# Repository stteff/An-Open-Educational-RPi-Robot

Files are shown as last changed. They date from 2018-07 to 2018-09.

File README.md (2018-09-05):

# Table of Contents

* [What is OpEdRo](#opedro-an-open-educational-rpi-robot)
* [Main Components](#main-components)
* [Circuit Diagram](#circuit-diagram)
* [(Raspberry Pi) Software Prerequisites](#raspberry-pi-software-prerequisites)
  * [Step 1: Installing and Setting up Raspberry Pi's Operating System](#step-1-installing-and-setting-up-raspberry-pis-operating-system)
  * [Step 2: Installing Necessary Python Libraries](#step-2-installing-necessary-python-libraries)
* [Remote Access Rapsberry Pi's Command Line Interface (CLI)](#remote-access-rapsberry-pis-command-line-interface-cli)
* [The Control Computer](#the-control-computer-----)
* [Scratch Project](#scratch-project-----)
* [Licenses](#licenses)

---

# [OpEdRo] An-Open-Educational-(RPi)-Robot

An Educational Robotic Platform, Raspberry Pi based, using Open Technologies. Remotely programmable from Scratch to move specific distances, to turn specific angles, to get distance from obstacle, to get environment temperature, to speak text and contents of variables in more than 30 languages.

---

*`This project is in active development. Additions will be taking place on a regular basis`*

---

## `OpEdRo:-----`
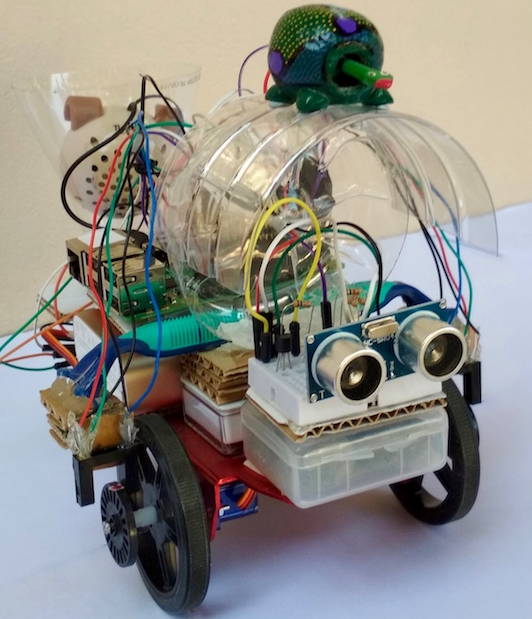
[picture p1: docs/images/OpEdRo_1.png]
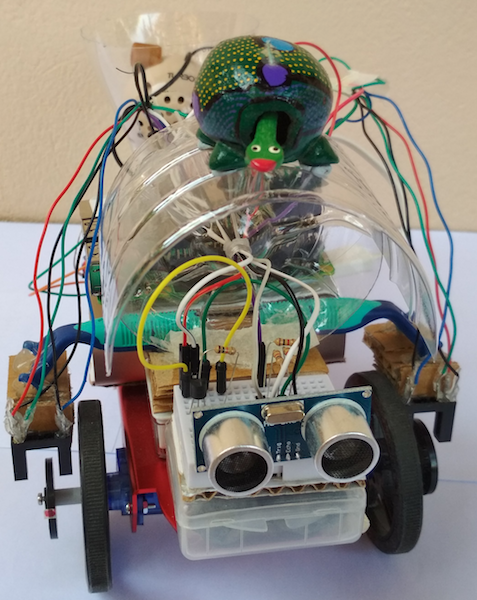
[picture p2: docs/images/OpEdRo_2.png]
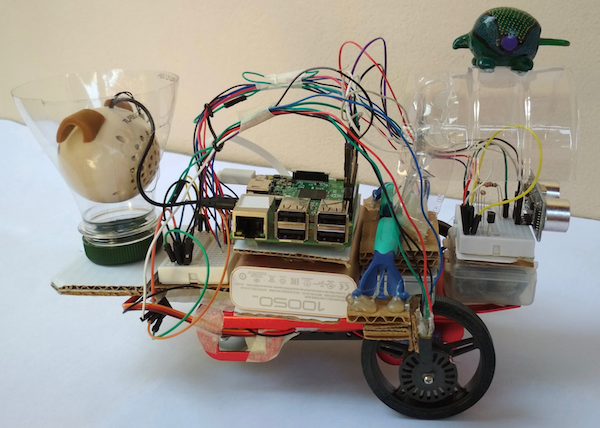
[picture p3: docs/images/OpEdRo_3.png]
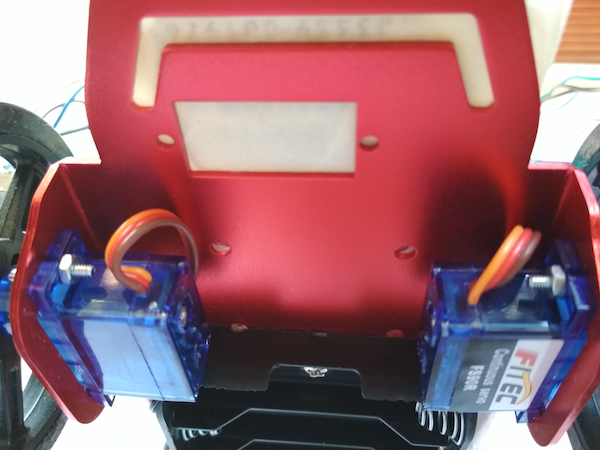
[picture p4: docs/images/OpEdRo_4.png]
     
### Main Components:

chassis Raspberry Pi 3 servo motor photoelectric Encoder disk servo wheel digital thermometer ultrasonic sensor ball caster Battery holder

  * A robot chassis appropriate to host the following parts
  * A Rapsberry Pi 3 model B
  * 2 continuous rotation micro servo motors, fitable to robot chassis
  * 2 photoelectric sensors
  * 2 encoder disks
  * 2 servo mount wheels
  * 1 digital thermometer (DS18B20)
  * 1 ultrasonic distance sensor (HC-SR04)
  * 1 ball caster
  * 1 battery holder for 4xAA to power the servos
  * 1 power bank for Raspberry Pi
  * 1 small portable speaker with 3.5 mm jack (for the speech engine)
  
### Circuit Diagram
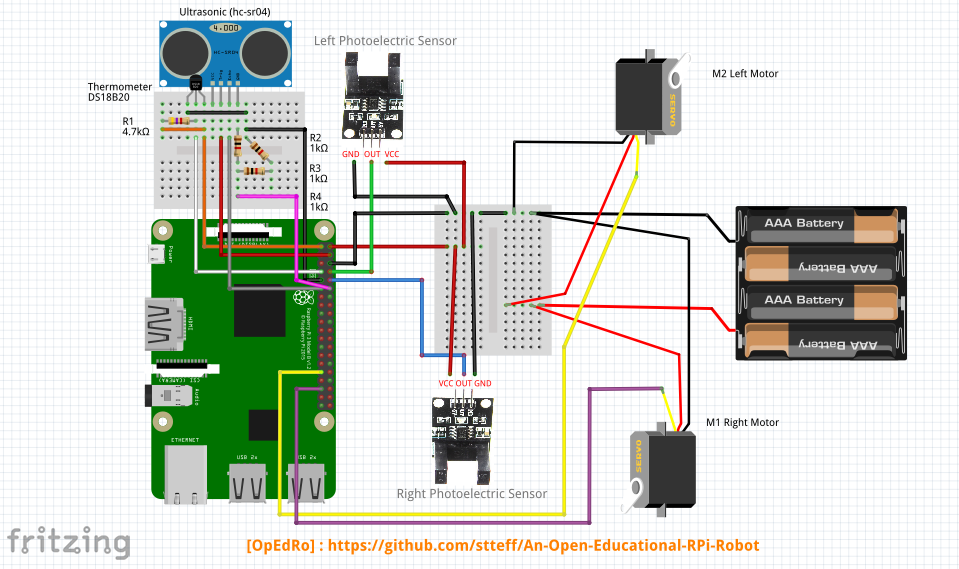
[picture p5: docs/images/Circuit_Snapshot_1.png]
Circuit diagram
  
  
### (Raspberry Pi) Software Prerequisites: 

  * Operating system
    * Raspbian Jessie or Stretch Lite (Lite version uses lower computer resources)
  * Python 2.7.x (inclluded with OS)
  * Python packages / modules:
    * [RPi.GPIO](https://sourceforge.net/p/raspberry-gpio-python/wiki/Home/ "RPi.GPIO Wiki") (a class to control the GPIO on a Raspberry Pi, included with OS)
    * [pigpio](http://abyz.me.uk/rpi/pigpio/index.html "The pigpio Documentation") (a library supporting hardware timed servo pulses)
    * [scratchpy](https://github.com/pilliq/scratchpy "Python interface to Scratch") (a python client for Scratch)
    * [espeak](http://espeak.sourceforge.net/ "espeak Documentation") (a text to speech engine)
    * [w1thermsensor](https://github.com/timofurrer/w1thermsensor "Python package for the DS18B20 sensor") (a library for the DS18B20 temperature sensor)
  
---
### Step 1: Installing and Setting up Raspberry Pi's Operating System
---
  1. > Download [Raspbian Stretch Lite](https://www.raspberrypi.org/downloads/raspbian/) image file
  2. > Unzip the compressed file
  3. > Use the [Etcher](https://etcher.io/) SD card utility (or a similar one) to transfer the Raspbian to the SD card
  4. > Connect Raspberry Pi to an internet network using an Ethernet cable and boot
  5. > Log in as *pi* user
  6. > Invoke the configuration utility *raspi-config*, by typing at the command line interface:
     > ```
     > sudo raspi-config
     > ```
  7. > Enable remote command line access using ssh, in order to allow remote access to the robot:
  
     > 7a. Select *Interfacing Options:*
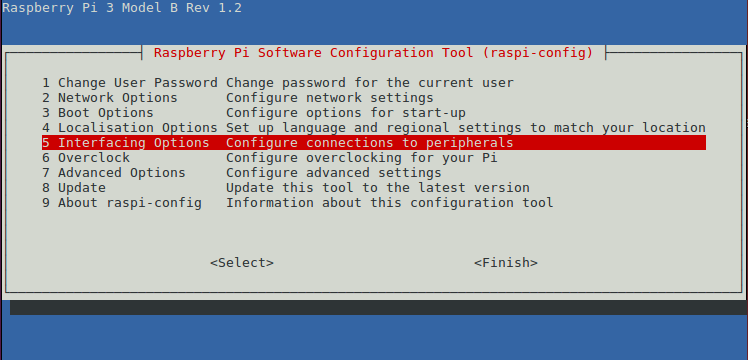
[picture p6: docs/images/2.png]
Step 7a
     > 
     
     > 7b. Select *SSH:*
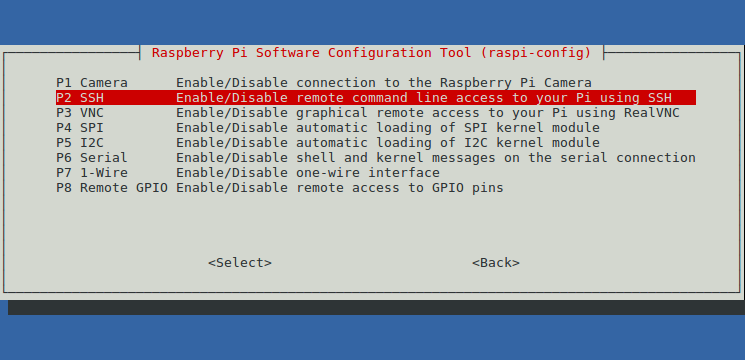
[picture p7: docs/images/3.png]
Step 7b
     > 

  8. > Set WiFi SSID and pass phrase of the network where robot will be connected:
  
     > 8a. Select *Network Options:*
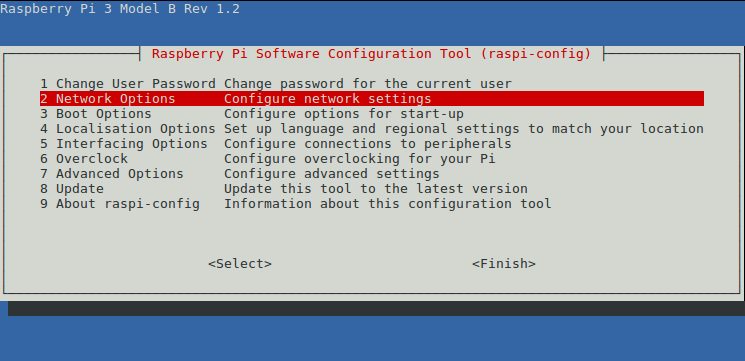
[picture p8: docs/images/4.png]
Step 8a
     > 
     
     > 8b. Select *Wi-fi:*
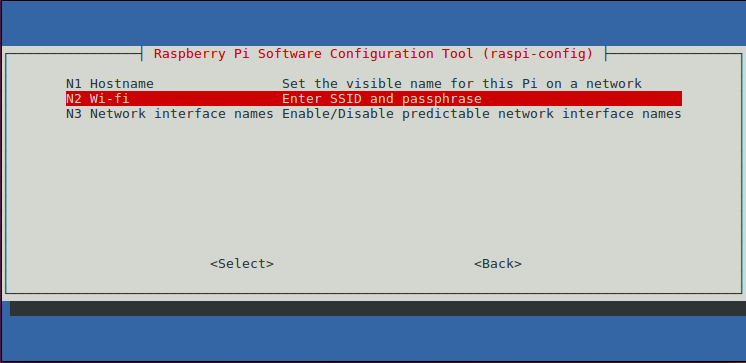
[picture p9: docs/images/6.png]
Step 8b
     > 
  9. > Check the wlan (wireless lan) IP assigned.
     
     > Exit raspi-config and type:
     > ```
     > ifconfig
     > ```
     > At the *wlan0:* part of the command output, the new IP should appear:
     >
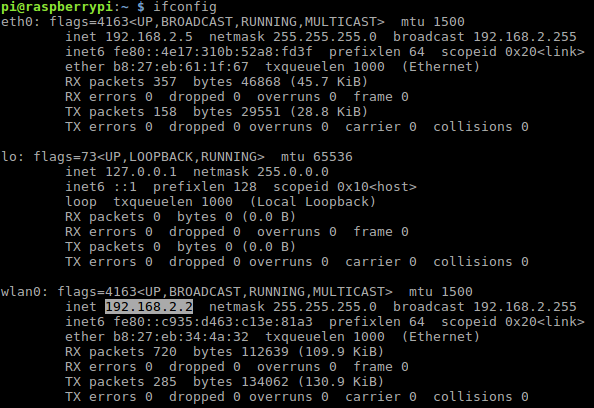
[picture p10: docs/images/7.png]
Step 9
     > 
  10. > Set a Static IP for the Raspberry Pi [Optional]
  
      > You will need:
      > - a valid static IP address (at the example below, *192.168.2.200*)
      > - the router's and domain_name_servers' IP addresses (usually same IP for both, at the example below *192.168.2.1*)
      >
      
      > At the command line type:
      > ```
      > sudo nano /etc/dhcpcd.conf
      > ```
      > Go to the end of the file and type (adjust accordingly to your IPs):
      > ```
      > interface wlan0
      > static ip_address=192.168.2.200/24
      > static routers=192.168.2.1
      > static domain_name_servers=192.168.2.1
      > ```
      > Save changes, exit nano and reboot by typing:
      >
      > <p><kbd>Ctrl</kbd> + <kbd>O</kbd>  to confirm write to the file</p>
      > <p><kbd>Ctrl</kbd> + <kbd>X</kbd>  to exit the nano editor</p>
      >
      > `sudo reboot` for changes to take effect 
      
---
### Step 2: Installing Necessary Python Libraries
---
  1. > Update and upgrade installed packages:
  
     > ```
     > sudo apt-get update
     > sudo apt-get upgrade
     > ```
  2. > Install scratchpy:
  
     > Firstly obtain the python package manager, *pip*
     > ```
     > sudo apt-get install python-pip
     > ```
     
     > Then continue with the scratchpy:
     > ```
     > pip install scratchpy
     > ```
  3. > Install the pigpio library:
  
     > ```
     > wget abyz.co.uk/rpi/pigpio/pigpio.zip
     > unzip pigpio.zip
     > cd PIGPIO
     > make
     > sudo make install
     > ```
  4. > Install the espeak package:
  
     > ```
     > sudo apt-get install python-espeak
     > ```
  5. > Setting the DS18B20 thermometer:
     
     > 5a. Install the w1thermsensor package:
     > ```
     > sudo apt-get install python-w1thermsensor
     > ```
     
     > 5b. Allow hardware initialisation for the sensor.
           At the command line type:
      
     > ```
     > sudo nano /boot/config.txt
     > ```
     > Go to the end of the file and type:
     > ```
     > dtoverlay=w1-gpio
     > ```
     > Save changes, exit nano and reboot by typing:
     >
     > <p><kbd>Ctrl</kbd> + <kbd>O</kbd>  to confirm write to the file</p>
     > <p><kbd>Ctrl</kbd> + <kbd>X</kbd>  to exit the nano editor</p>
     >
     > `sudo reboot` for changes to take effect
  
---
### Remote Access Rapsberry Pi's Command Line Interface (CLI)
---
Knowing the IP address of the Raspberry Pi, from Step 1 [9. & 10.] above (assume that is ~192.168.2.200~ for demonstration purposes), one could connect to its CLI from another computer of the same network
  * If you are on a Windows environment, you will firstly need to install an *ssh terminal client* program (e.g. [PuTTY](https://www.putty.org/)) and configure it to connect to ~192.168.2.200~
  * If you are on a Unix environment, open a terminal window and type:
  
    `ssh pi@192.168.2.200`

## `The Control Computer:-----`
Any computer capable to run Scratch 1.4 (the version supporting the [Mesh](https://en.scratch-wiki.info/wiki/Mesh) method), connected to the same LAN as Raspberry Pi, could become the robot control center:

  1. > [Download Scratch 1.4](https://scratch.mit.edu/scratch_1.4/)
  2. > After opening the application, follow the [instructions](https://en.scratch-wiki.info/wiki/Mesh#Mesh_by_Modification_of_Scratch) for modifying Scratch to enable **Mesh.** You may require administrator privileges
       
        or
     
     > if you are on Windows environment, replace your *scratch.image* file in the **scratch** directory (Program files folder), with the one having Mesh enabled [Windows only](/docs/scratch.image)
  3. > If **Mesh** is not activated, *Host Mesh* by pressing and mouse clicking: <p><kbd>Shift</kbd> + <kbd>Share</kbd> from Scratch menu
  
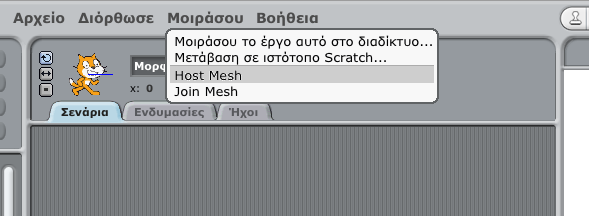
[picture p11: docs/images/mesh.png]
enabling Mesh
     > 
  
## `Scratch Project:-----`
**Examples**: -
Press on one of the images below to download the whole Scratch project
(there will be an english version soon..)

The four images correspond to the four sprites of the file *OpEdRo_Examples.sb*

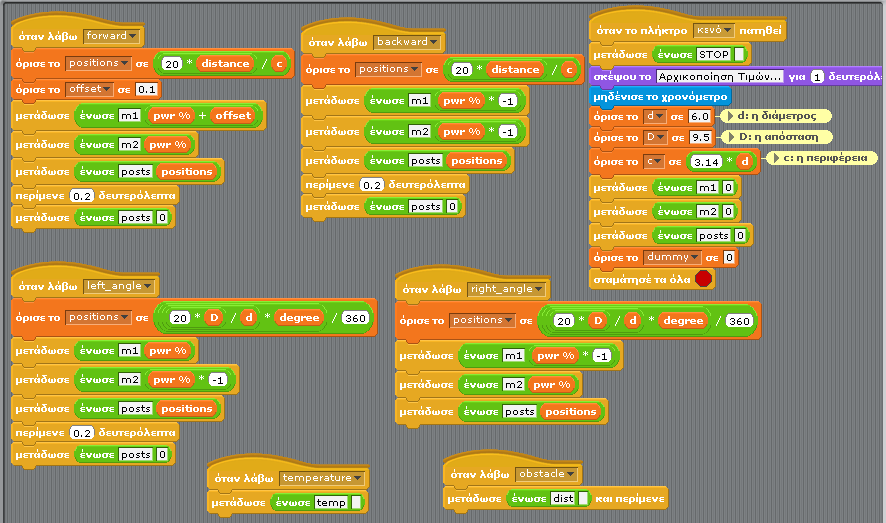
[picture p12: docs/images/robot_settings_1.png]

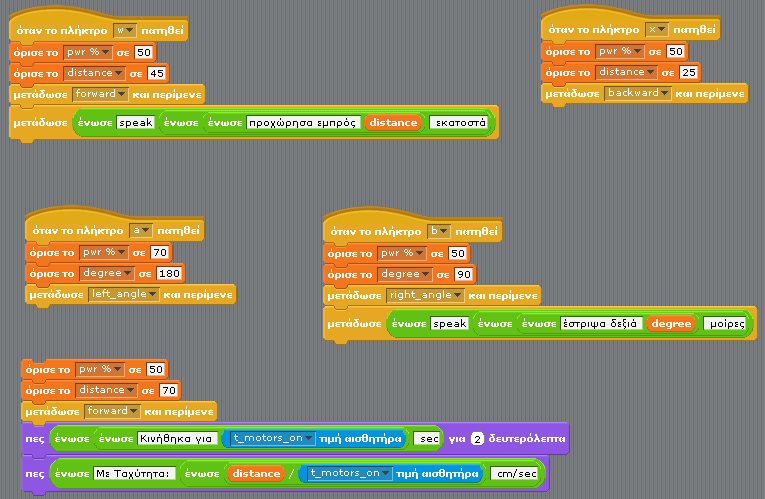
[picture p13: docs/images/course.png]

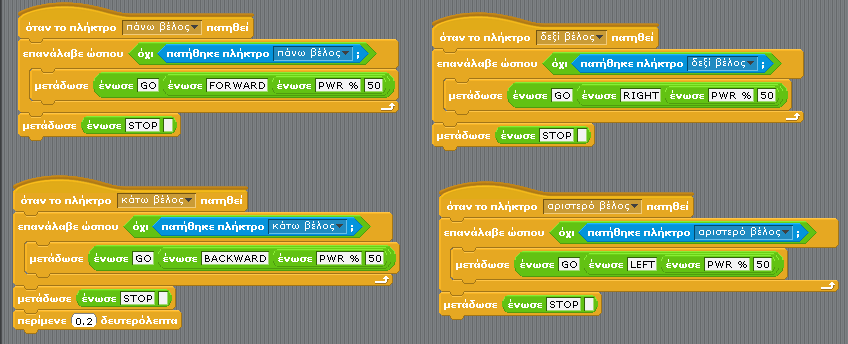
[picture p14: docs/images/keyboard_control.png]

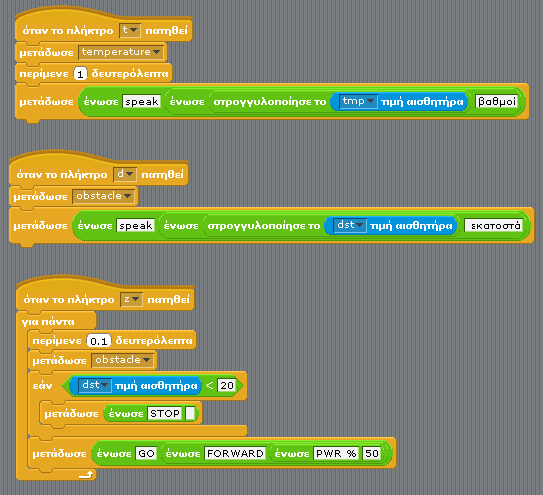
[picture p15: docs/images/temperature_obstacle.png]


## Licenses
Software License:

License (https://www.gnu.org/licenses/gpl-3.0.txt)

Non Software material License:



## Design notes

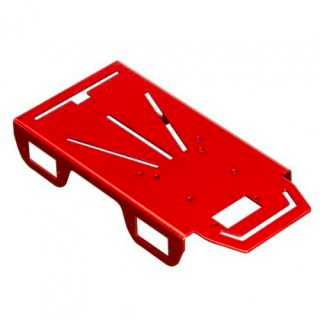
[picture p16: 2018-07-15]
docs/images/Robot_chassis.png

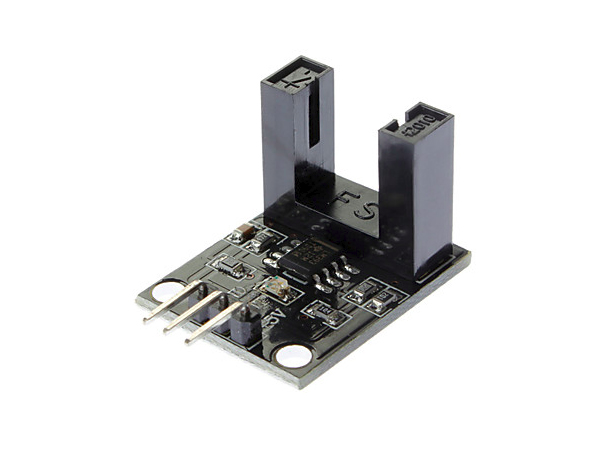
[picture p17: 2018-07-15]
docs/images/Photoelectric_sensor.png

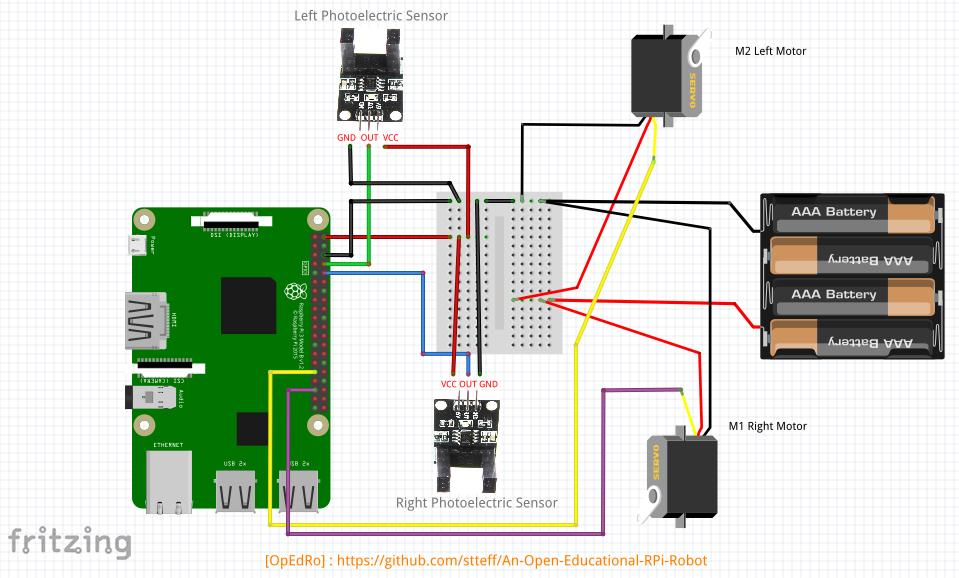
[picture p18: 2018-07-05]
docs/images/Circuit_Snapshot.png

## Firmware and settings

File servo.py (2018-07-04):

''' A simple servo class based on the pigpio library
    http://abyz.me.uk/rpi/pigpio/pigs.html#S/SERVO
'''

import time
from subprocess import check_call

# *** GPIO BCM pin numbering is used ***

# Class for the ordinary servo motor
class Servo:
    def __init__(self, pin):
        self.pin = pin

    def forward(self, speed):
        #proc = check_call(["pigs", "s", "6", str(speed)])
        if speed >=0 and speed <= 600:
            speed += 1500
            proc = check_call(["pigs", "s", str(self.pin), str(speed)])
        else:
            print ("Valid servo values: [0 - 600] microseconds")
            self.stop()
#            exit()

    def backward(self, speed):
        if speed >=0 and speed <= 600:
            speed = 1500 - speed
            proc = check_call(["pigs", "s", str(self.pin), str(speed)])
        else:
            print ("Valid servo values: [0 - 600] microseconds")
            self.stop()
#            exit()

    def stop(self):
        #proc = check_call(["pigs", "s", "6", "0"])
        proc = check_call(["pigs", "s", str(self.pin), "0"])

# Class for the opposite servo motor, positioned UpSide-Down on the robot chassis
class UDServo:
    def __init__(self, pin):
        self.pin = pin

    def forward(self, speed):
        if speed >=0 and speed <= 600:
            speed = 1500 - speed
            proc = check_call(["pigs", "s", str(self.pin), str(speed)])
        else:
            print ("Valid servo values: [0 - 600] microseconds")
            self.stop()
#            exit()

    def backward(self, speed):
        if speed >=0 and speed <= 600:
            speed += 1500
            proc = check_call(["pigs", "s", str(self.pin), str(speed)])
        else:
            print ("Valid servo values: [0 - 600] microseconds")
            self.stop()
#            exit()

    def stop(self):
        proc = check_call(["pigs", "s", str(self.pin), "0"])

if __name__ == '__main__':
    M1=Servo(6)
    M2=UDServo(19)
    M1.forward(speed=200)
    M2.forward(speed=200)
    time.sleep(2)
    M1.stop()
    M2.stop()
    time.sleep(1)
    M1.backward(200)
    M2.backward(200)
    time.sleep(2)
    M1.stop()
    M2.stop()

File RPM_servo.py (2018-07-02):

# Regulates servo speed to a specified RPM 
# (SP_rpm variable) using Propotional Control.
# Used for a two wheels robot, to find out the necessary
# pulse width for each servo. 

import RPi.GPIO as GPIO
import time
from subprocess import check_call
from servo import Servo, UDServo

# The Normal servo
M2 = Servo(6) 
# GPIO pin of photointerrupter sensor
sensor_2 = 14

# The UpSide Down servo
M1 = UDServo(19) 
# GPIO pin of photointerrupter sensor
sensor_1 = 15

GPIO.setmode(GPIO.BCM)
GPIO.setup(sensor_1,GPIO.IN)
GPIO.setup(sensor_2,GPIO.IN)

# Number of Encoder's Disk Positions
encoder_pos = 20
#encoder_pos = 10

# The initial speed (pulse width in microseconds)
# M1 and M2 at 1680 and 1650 respectively
#speed_1 = 1650
#speed_2 = 1650

speed_1 = 150
speed_2 = 150

# Desired RPM
SP_rpm = 70
count_1 = 0
count_2 = 0

# start and end timers
start_1 = 0
start_2 = 0
end_1 = 0
end_2 = 0

def set_start_1():
 	global start_1
 	start_1 = time.time()

def set_start_2():
 	global start_2
 	start_2 = time.time()

# ---------------------------

def set_end_1():
 	global end_1
 	end_1 = time.time()

def set_end_2():
 	global end_2
 	end_2 = time.time()

# ---------------------------

def inc_speed_1(d):
    global speed_1
    speed_1 += d
    M1.forward(speed_1)
    print ("speed_1: ",speed_1)

def inc_speed_2(d):
    global speed_2
    speed_2 += d
    M2.forward(speed_2)
    print ("speed_2: ",speed_2)

# ---------------------------

def dec_speed_1(d):
    global speed_1
    speed_1 -= d
    M1.forward(speed_1)
    print ("speed_1: ",speed_1)

def dec_speed_2(d):
    global speed_2
    speed_2 -= d
    M2.forward(speed_2)
    print ("speed_2: ",speed_2)

# ---------------------------

def calc_rpm_1():
    global rpm_1
    # The end time
    set_end_1()
    # The net time taken to complete [encoder_pos=20] positions i.e. 1 full
    # rotation in seconds
    dt_1 = end_1 - start_1
    #dt_1 = 2*(end_1 - start_1)
    # 1 Revolution Per Minute ***
    rpm_1 = 60 / dt_1
    print ("RPM_1: ",rpm_1)

def calc_rpm_2():
    global rpm_2
    # The end time
    set_end_2()
    # The net time taken to complete [encoder_pos=20] positions i.e. 1 full
    # rotation in seconds
    dt_2 = end_2 - start_2
    #dt_2 = 2*(end_2 - start_2)
    # 1 Revolution Per Minute ***
    rpm_2 = 60 / dt_2
    print ("RPM_2: ",rpm_2)
# ---------------------------

def get_rpm_1(c):
    global count_1
    global speed_1

#    if not count_1:
        # When count==0, start the timer
#        set_start_1()
#        count_1 += 1
#    else:
#        count_1 += 1

    if count_1 == 0:
        # When count==0, start the timer
        set_start_1()
    count_1 += 1

    if count_1==encoder_pos:

        calc_rpm_1()

        # This is the Propotional Control
        err_1 = rpm_1 - SP_rpm 
        if err_1 > 0:

            if err_1 >= 20:
                dec_speed_1(10)
            if err_1 < 20 and err_1 >= 10:
                dec_speed_1(5)
            if err_1 < 10 and err_1 >= 5:
                dec_speed_1(2)
            if err_1 < 5 and err_1 >= 2:
                dec_speed_1(1)
           # if err_1 < 1:
           #     print ("speed_1: ",speed_1)

            #print ("speed_1: ",speed_1)

        if err_1 < 0:
            #print("err_1: ", err_1)
            err_1 = abs(err_1)
            if err_1 >= 20:
                inc_speed_1(10)
            if err_1 < 20 and err_1 >= 10:
                inc_speed_1(5)
            if err_1 < 10 and err_1 >= 5:
                inc_speed_1(2)
            if err_1 < 5 and err_1 >= 2:
                inc_speed_1(1)
            #if err_1 < 1:
            #    print ("speed_1: ",speed_1)
            
            #print ("speed_1: ",speed_1)


        calc_rpm_1()

        print
        # Reset count
        count_1 = 0

# ---------------------------

def get_rpm_2(c):
    global count_2
    global speed_2

    if count_2 == 0:
        # When count==0, start the timer
        set_start_2()
    count_2 += 1

    if count_2==encoder_pos:

        calc_rpm_2()

        # This is the Propotional Control
        err_2 = rpm_2 - SP_rpm 
        if err_2 > 0:

            if err_2 >= 20:
                dec_speed_2(10)
            if err_2 < 20 and err_2 >= 10:
                dec_speed_2(5)
            if err_2 < 10 and err_2 >= 5:
                dec_speed_2(2)
            if err_2 < 5 and err_2 >= 2:
                dec_speed_2(1)
            #if err_2 < 1:
            #    print ("speed_2: ",speed_2)

            #print ("speed_2: ",speed_2)

        if err_2 < 0:
            #print("err_2: ", err_2)
            err_2 = abs(err_2)
            if err_2 >= 20:
                inc_speed_2(10)
            if err_2 < 20 and err_2 >= 10:
                inc_speed_2(5)
            if err_2 < 10 and err_2 >= 5:
                inc_speed_2(2)
            if err_2 < 5 and err_2 >= 2:
                inc_speed_2(1)
            #if err_2 < 1:
            #    print ("speed_2: ",speed_2)

            #print ("speed_2: ",speed_2)
            
        calc_rpm_2()

        print
        # Reset count
        count_2 = 0

# ---------------------------

#proc1 = check_call(["pigs", "s", "6", str(speed)])
M1.forward(speed_1)
#M1.backward(speed_1)
GPIO.add_event_detect(sensor_1, GPIO.RISING, callback=get_rpm_1)

M2.forward(speed_2)
#M2.backward(speed_2)
GPIO.add_event_detect(sensor_2, GPIO.RISING, callback=get_rpm_2)

try:
 	while True: # create an infinte loop to keep the script running
 	 	time.sleep(0.1)
except KeyboardInterrupt:
    print "  Quit"
    GPIO.cleanup()
    M1.stop()
    M2.stop()
    exit()

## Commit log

2018-07-01 The servo folder for the Class and Test files
2018-07-01 A basic Class for the servos
2018-07-01 Test program to find servos produced pulse_widths for a given RPM
2018-07-01 The main program running on Raspberry Pi
2018-07-01 Comments for a Short Description of the program
    [RPM_servo.py]
2018-07-02 determines servo pulse widths for a given RPM
2018-07-05 Snapshot of Circuit
    [OpEdRo Circuit Diagram.fzz]
2018-07-05 Fritzing Diagram
    [Circuit_Diagram.fzz]
2018-07-05 Image of the circuit
2018-08-31 Supporting ultrasonic & temperature sensors
2018-08-31 Added Ultrasonic & temperature sensors
    [OpEdRo Circuit Diagram_1.fzz]
2018-08-31 Fritzing - Added ultrasonic & temperature sensors
    Fritzing Diagram
    [OpEdRo Circuit Diagram_1.fzz]
2018-08-31 Update circuit diagram
2018-09-02 Added temperature and ultrasonic sensors support
2018-09-04 Additional License for all non software material

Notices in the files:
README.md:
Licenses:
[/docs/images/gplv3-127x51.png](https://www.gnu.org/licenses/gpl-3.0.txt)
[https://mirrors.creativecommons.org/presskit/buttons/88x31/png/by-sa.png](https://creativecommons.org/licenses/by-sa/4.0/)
